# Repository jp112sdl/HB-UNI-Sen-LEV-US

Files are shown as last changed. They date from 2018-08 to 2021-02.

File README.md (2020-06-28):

# HB-UNI-Sen-LEV-US
#### Füllstandsensor für HomeMatic

Um die Geräteunterstützung zu aktivieren, wird die aktuellste Version des [JP-HB-Devices Addon](https://github.com/jp112sdl/JP-HB-Devices-addon/releases/latest) benötigt!
<br/>
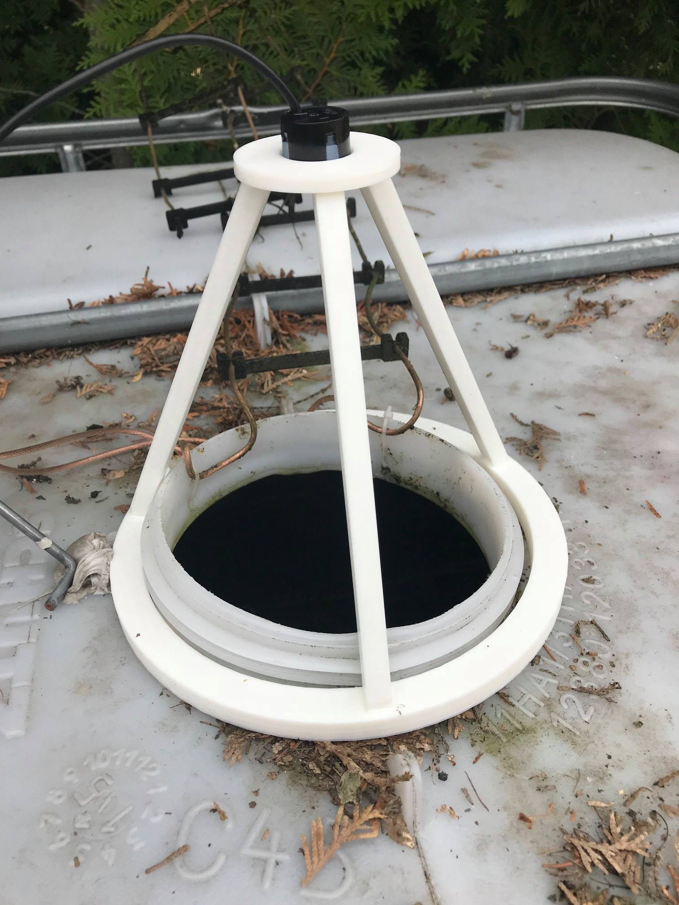
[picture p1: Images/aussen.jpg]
<br/>
_Der erste Prototyp_

#### Bauteile
- Batteriehalter für 3 oder 4 Batterien
- Ultraschallsensor:
  - z.B. [JSN-SR04T V2.0](https://de.aliexpress.com/item/Integrated-Ultrasonic-Module-Distance-Measuring-Sensor-Module-Reversing-Radar-Waterproof/32312190912.html)
    - **Hinweis:** Unbedingt die **V2.0** nehmen, weil diese auch mit 3.3V zuverlässig arbeitet!
  - oder [US-100](https://eckstein-shop.de/Adafruit-US-100-Ultrasonic-Distance-Sensor-3V-or-5V-Logic)  
  - oder MaxBotix [MaxSonar MB1040, LV-MaxSonar-EZ4](https://de.aliexpress.com/item/NEW-Mini-uav-obstacle-avoidance-ultrasonic-ranging-module-MB1040-High-Performance-Sonar-Range-Finder/32862912642.html)
  
- [CC1101 (868MHz)](https://de.aliexpress.com/item/CC1101-Wireless-Module-Long-Distance-Transmission-Antenna-868MHZ-M115-For-FSK-GFSK-ASK-OOK-MSK-64/32635393463.html) 
- [Arduino Pro Mini 3.3V/8MHz](https://de.aliexpress.com/item/Free-Shipping-1pcs-pro-mini-atmega328-Pro-Mini-328-Mini-ATMEGA328-3-3V-8MHz-for-Arduino/32342672626.html)
- Kleinteile...
  - 1x LED
  - 1x Taster
  - Widerstände, je 1x 330 Ohm, 100kOhm, 470kOhm

#### Verdrahtung
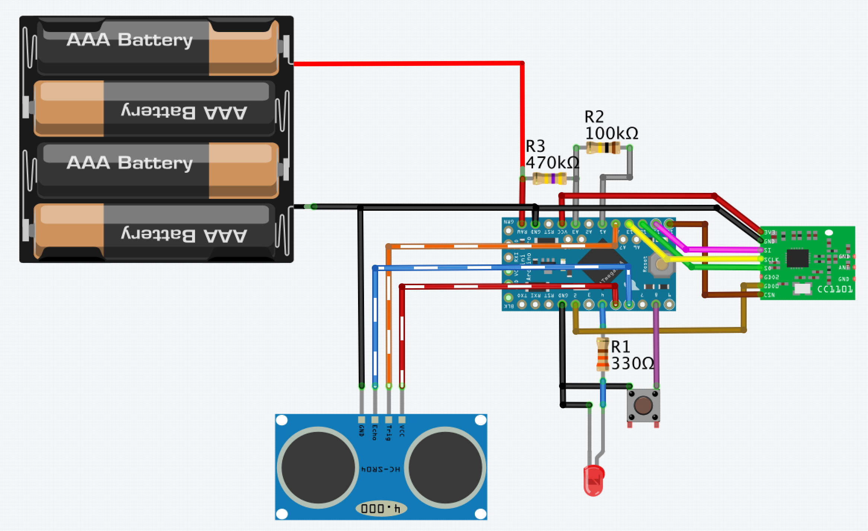
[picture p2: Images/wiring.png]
wiring


**oder mit Temperaturkompensation:**
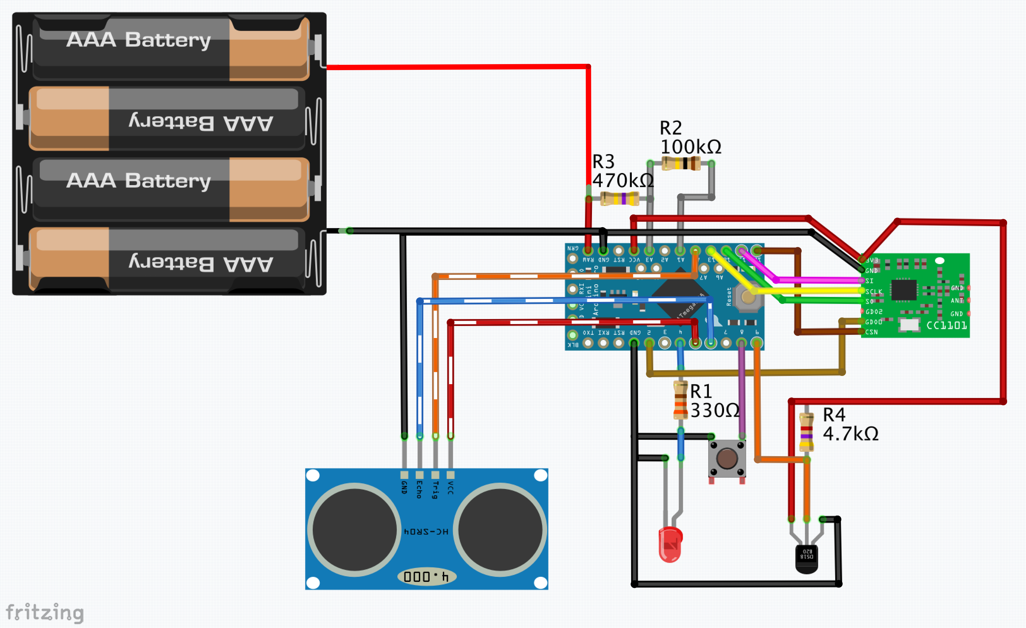
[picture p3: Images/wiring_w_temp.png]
wiring_w_temp


**Bei Verwendung des MaxSonar Sensors ist der PW-Pin an den SENSOR_ECHO_PIN anzuschließen. Der SENSOR_TRIG_PIN wird nicht verwendet.**

#### CCU Geräteeinstellungen
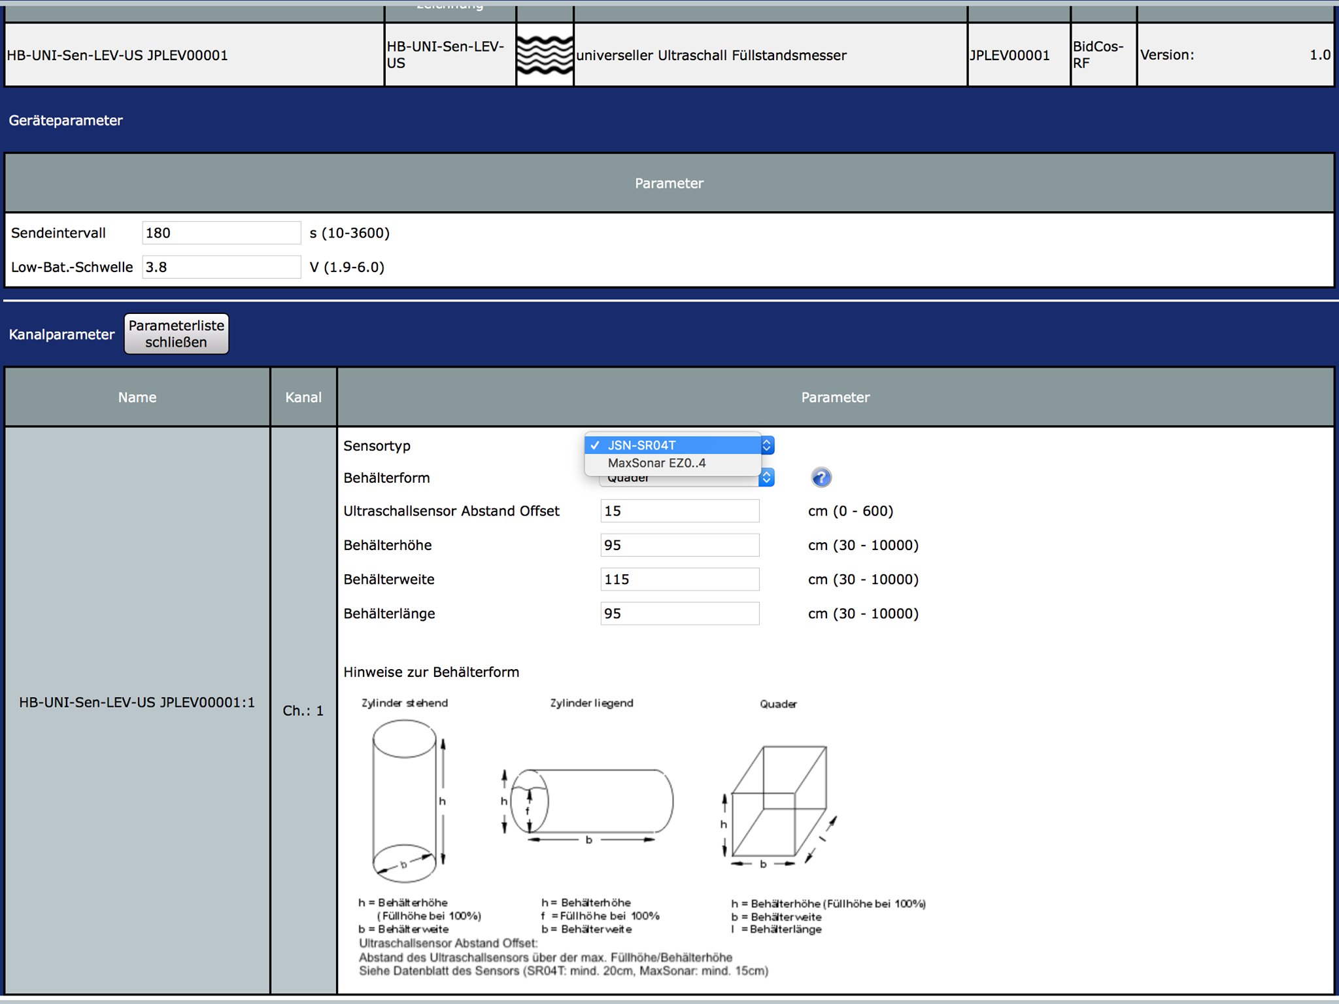
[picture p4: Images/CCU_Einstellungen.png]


Bei Verwendung des **US-100** ist der **JSN-SR04T** auszuwählen

#### CCU Anzeige der Werte
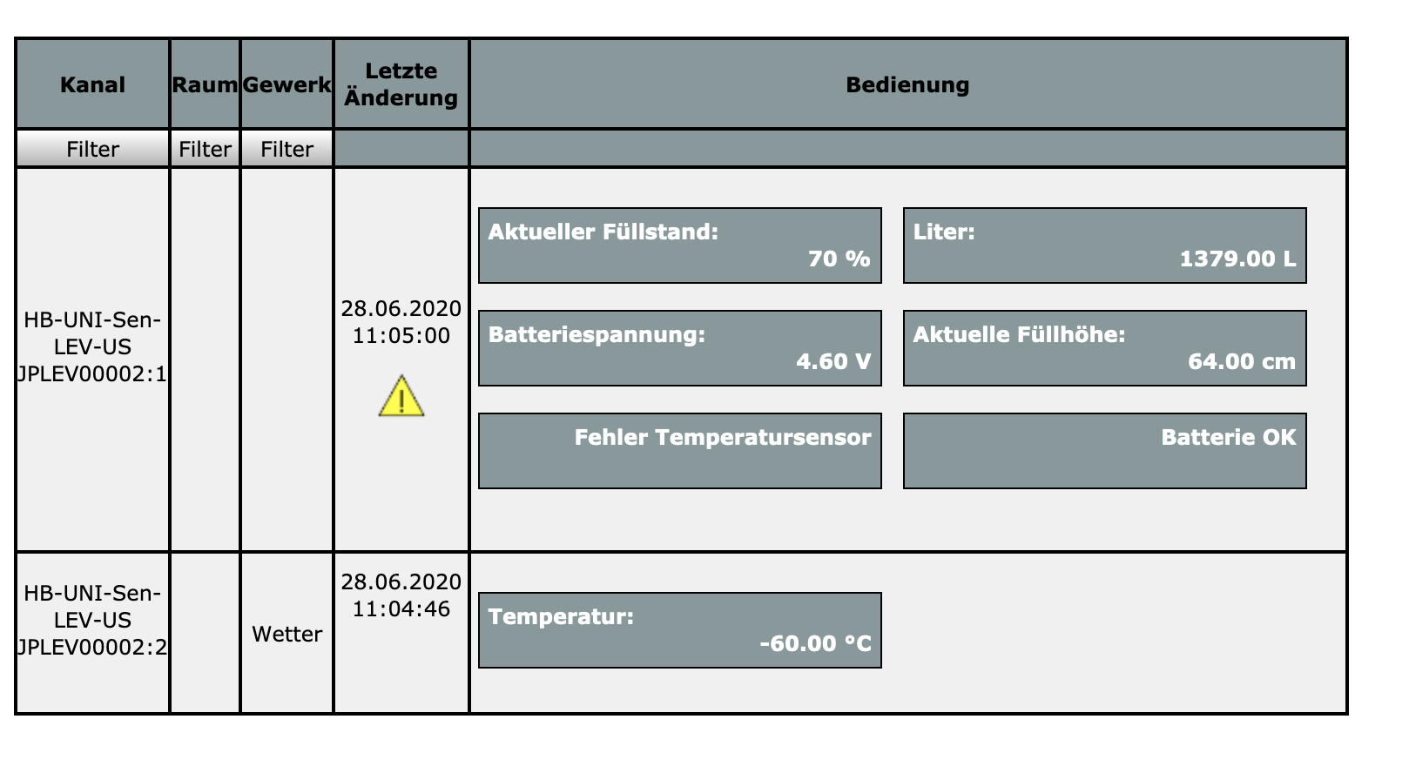
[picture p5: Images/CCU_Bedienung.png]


#### Halterung / Aufhängung
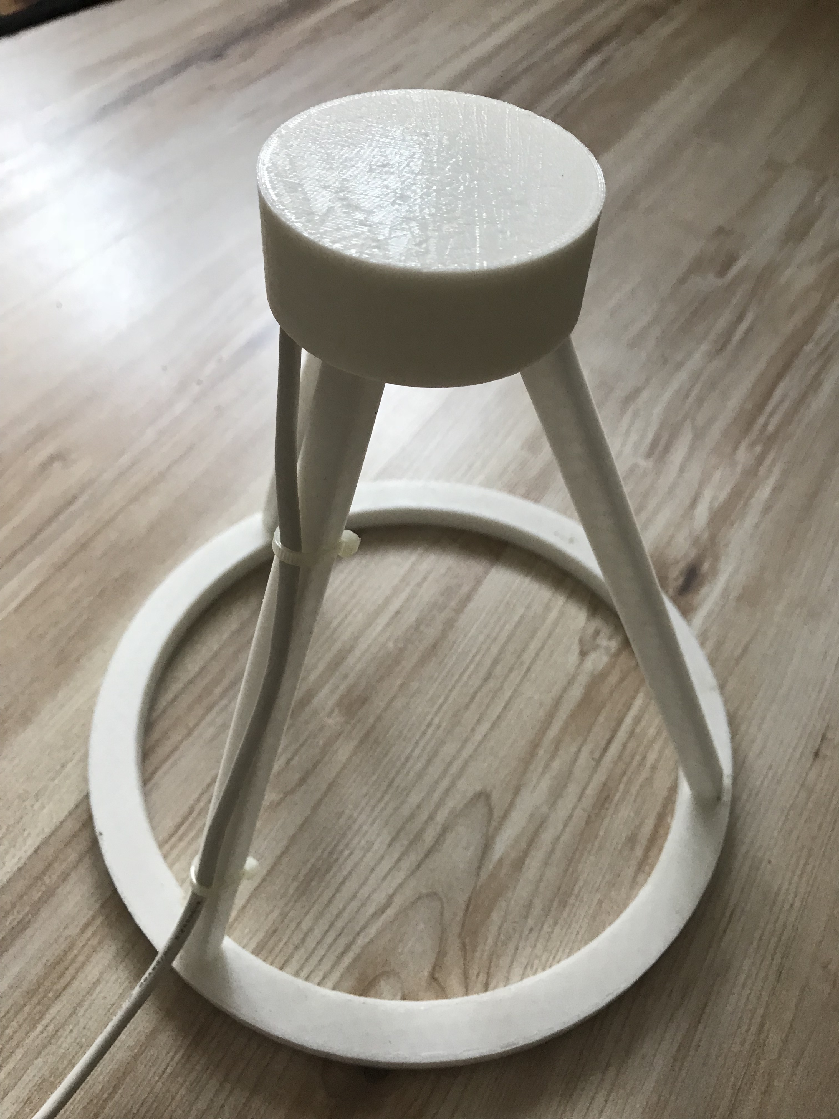
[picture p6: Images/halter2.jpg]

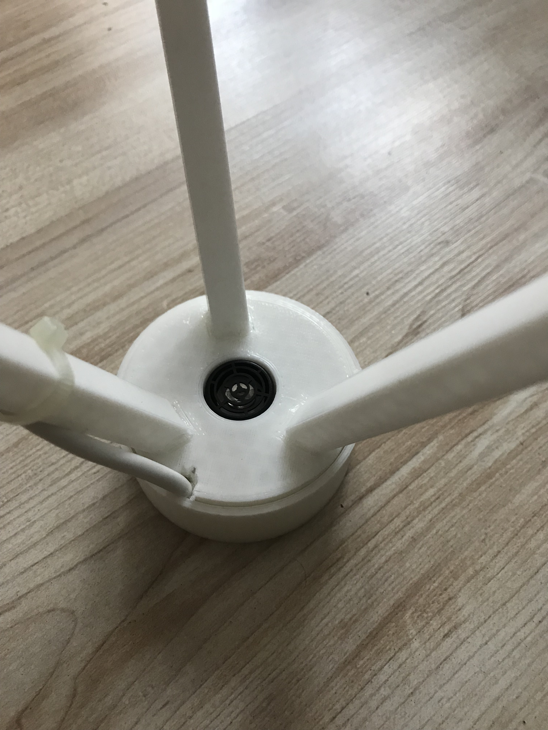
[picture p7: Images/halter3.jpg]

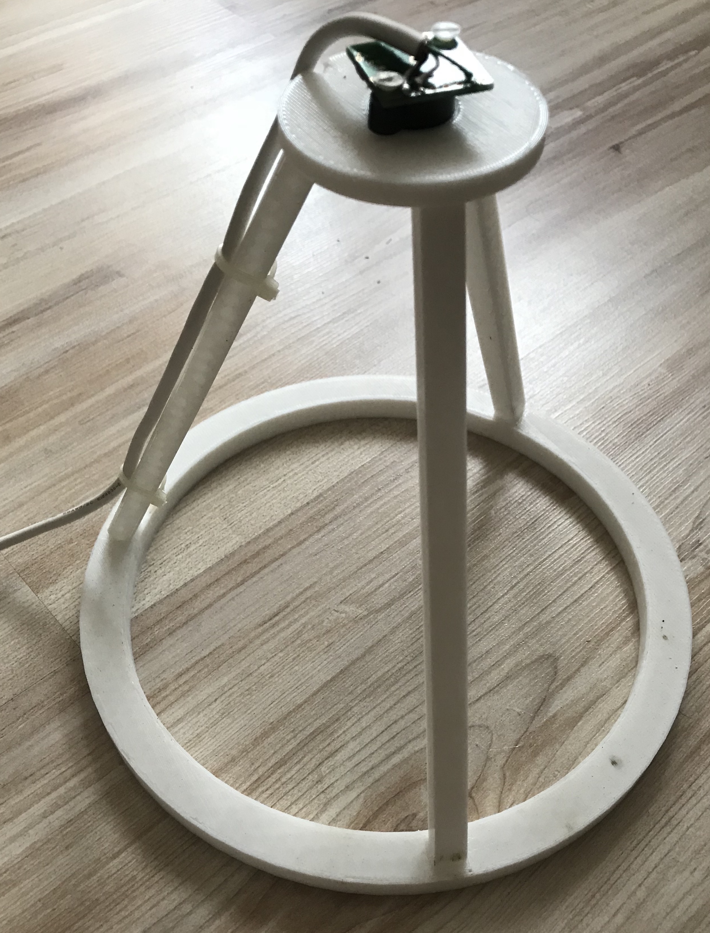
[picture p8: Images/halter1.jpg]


**Die Teile findet ihr bei Tinkercad:**
<br/>
[Stange für Höhe 20cm](https://www.tinkercad.com/things/iM7Yyc3prMh-ultraschallsensor-halterung-stange-20cm-hohe/editv2)<br/>
[Stange für Höhe 15cm](https://www.tinkercad.com/things/7xHuCkIllsB-ultraschallsensor-halterung-stange-15cm/editv2)<br/>
[Ringe](https://www.tinkercad.com/things/15f2ttggOnX-ultraschallsensor-halterung/editv2)<br/>
[Deckel](https://www.tinkercad.com/things/2bYtNM8HQ3f-ultraschallsensor-halterung-deckel/editv2)

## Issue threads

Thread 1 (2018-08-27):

kleine Anmerkungen zur Doku und Sensor

harvey637, 2018-08-27:
Hi Jerome,,
Klugscheisseralarm === winzige Anmerkung zur Doku
- ist MaxBotix == MaxSonar? bei den US-Wandlern steht MaxBotix, im unteren Text "Bei Verwendung des MaxSonar ...". Das kann Kleingeister eventuell verwirren.

- In dem Screenshot der Einstellungsseite steht unten "Siehe Datenblatt des Sensor SR04T: mind 20 cm...".
Trotzdem ist im Beispiel "SR04T" ausgewählt und "15 cm" eingetragen.

Nur so zum "alles richtig verständlich" machen, definitiv vielen Dank und keine Abwertung gemeint!!!
cu
Harvey

PS - ein paar Fragen:
- spielt die Temperatur keine Rolle? (schon minimal bei der Schallgeschwindigkeit:-)
- Fehlmessung etwa durch Plätschern beim Zulauf z.B. in einen Regenwassertank? 2*messen / Mittelwert?
- Einschränkung des Messwinkels um z.B. Zulauf-Wasserstrahl nicht zu erfassen (10cm Durchmesser Rohr?)

jp112sdl, 2018-08-27:
- MaxBotix ist der Hersteller, MaxSonar der Produktname (bzw. der Name der Produktfamilie)
- der Screenshot ist halt so... 🤓 der Offset muss individuell eingestellt werden.

- Temperatur ist bei den Distanzen wohl zu vernachlässigen, ich lass mich aber auch gern belehren, falls es Vorschläge zur Einberechnung gibt. Bisher stimmt die Abstandsmessung bei mir auf den Zentimeter genau

Generell sind die Projekte hier nach meinen persönlichen Anforderungen entstanden und "wie sie sind" veröffentlicht (in Bezug auf die letzten beiden Punkte). Sollten Anpassungen wegen eigener Bedürfnisse notwendig werden (denn irgendwie hat jeder andere Umgebungen), ist es dann wohl am besten, mit Forks zu arbeiten.

VG Jérôme

harvey637, 2018-08-27:
Hi,
mir geht es auch so, für die eigene Anforderung, da hat man ja ein Testumfeld in Praxis.
Bei mir eine Regenwassertonne. Schon der zweite Homematicsensor defekt - Schwitzwasser und
die Platine sitzt so flach, dass der kleinste Wassertropfen reicht :-(

Als ich damals nach Ideen googlete (vor homematic) fand ich eben auch eine Temperaturkompensation.
Ist ja vielleicht auch in dem Modul selbst eingebaut ... vielleicht.
Daher auch die Frage nach dem Winkel: bei mir strömt Wasser aus dem Regenfallrohr bei starkem
Regen sehr "intensiv" in die Tonne. Es gibt den Wasser"fall" mitten durch den Raum oberhalb
der Wassers, eventuell durch den Bereich, den der US-Sensor für die Messung braucht. Da war die
damalige Informationslage, dass der Sensor in eiem normalen 10cm Rohr oben drauf ist, das Rohr ein
paar seitliche Löcher hat damit der Wasserspiegel ansteigen kann und nur INNERHALB des Rohres
reflexionsarm die Oberfläche gemessen wird.
Teile sind in Bestellung :-) Und ich sehe mir das dann gerne "nach persönlichen Anforderungen" an.
Ergibt sich was interessantes melde ich mich hier, sonst ist alles ok!

Wenn ich doch nur mehr von Methoden und Templates verstehen würde, bin halt alter > 64 Jahre
Assemblerprogrammierer. Aber so ein Dutzend HB-Sensoren laufen schon, teils eben mit "persönlichen Anforderungen" modifiziert, die meist uninteressant sind.

Aber das Gesamtthema "Produktsicherheit" (Unterspannung fürhte bei mir zweimal zu Dutycycle mit
Verlust der Geräteverbindung), eben auch "Messung Wasserspiegel" und nicht "Messung was immer da so rumfliegt". Stetz zu wiederholen, ich achte die freiwillige Arbeit hier sehr und möchte nur - ohne zu stören - auch was zurückliefern.
cu
Haarvey

harvey637, 2018-08-27:
Ach, auf den Fotos kann ich auch erkennen, das derjenige auch anscheinend ähnlich schlechte
Erfahrungen mit dem kapazitiven HM-Füllstandssensor hat, die Kabel mit den Abstandhaltern
ist ja gut zu erkennen.

jp112sdl, 2018-08-27:
Derjenige bin ich... 😄
Der kap. Sensor hat mich sehr enttäuscht. Deshalb nun der Versuch mit Ultraschall.

Closed 2018-08-27.

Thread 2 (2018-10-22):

In function 'void setup()':  HB-UNI-Sen-LEV-US:318:19: error: 'printDeviceInfo' was not declared in this scope

fastsonic, 2018-10-22:
Hi,
not sure how to fix:
Version of Arduino 1.8.7
Error:
C:\xxxxxxxxxxxxxxxxxxxxxxxxxxxxxxxxxx\HB-UNI-Sen-LEV-US-4d6f7bfa74beb84f3a6f04ccf81aa3cc47c522d0\HB-UNI-Sen-LEV-US\HB-UNI-Sen-LEV-US.ino: In function 'void setup()':

HB-UNI-Sen-LEV-US:318:19: error: 'printDeviceInfo' was not declared in this scope

jp112sdl, 2018-10-22:
Hi,

just comment line [#318](https://github.com/jp112sdl/HB-UNI-Sen-LEV-US/blob/4d6f7bfa74beb84f3a6f04ccf81aa3cc47c522d0/HB-UNI-Sen-LEV-US.ino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):
`//printDeviceInfo();`

Closed 2018-10-23.

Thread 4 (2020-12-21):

jp112sdl / HB-UNI-Sen-LEV-US

Passagier, 2020-12-21:
Hallo Jerome,

ich habe den HB-UNI-Sen-LEV-US nachgebaut wie so einige andere Projekte von Dir auch -  und aktuelle Versionen verwendet, funktioniert alles sehr sehr gut, allerdings habe ich ein kleines Problem nur bei dem HB-UNI-Sen-LEV-US, wenn ich die Werte für Sendeintervall und oder Low-Bat.-Schwelle ändern möchte, werden diese tatsächlich nicht übernommen, es bleibt bei den Defaultwerten Sendeintervall= 180 und Low-Bat.-Schwelle= 2.2
wie kann ich das beheben?

Beste Grüße

jp112sdl, 2020-12-21:
Nutzt du gerade CCU FW 3.55.5 ?
Da ist ein Bug drin... du kannst bei keinem Gerät irgendwelche Werte mehr ändern

Passagier, 2020-12-21:
Ja ich habe die CU FW 3.55.5,
stimmt, habe ich gerade beim HB-UNI-Sen-TEMP-DS18B20 probiert gleiches Problem...
dachte dass er da die Werte übernommen hatte..
Allerdings kann ich die anderen Werte wie Höhe und Breite beim HB-UNI-Sen-LEV-US problemlos ändern
Ist der Bug behebbar oder gibt es ein Workarround?

jp112sdl, 2020-12-21:
Workaround: webui.js patchen
https://github.com/jens-maus/RaspberryMatic/blob/master/buildroot-external/patches/occu/0098-WebUI-Fix-ProofAndSetValue.patch

Ansonsten auf neue CCU FW warten, oder Downgrade machen

Passagier, 2020-12-21:
Sehr guter Tipp, danke hat funktioniert. 👍

Passagier, 2020-12-23:
Hallo Jerome,
ich muss noch einmal nachhacken,
Nach dem patchen der Webui, kann ich die Konfigurationsdaten eintragen und senden, diese werden aber erst übernommen, wenn ich kurzdarauf den Configbuttion am HB-UNI-Sen-LEV-US betätige oder es kurz vom Strom nehme und dadurch neu gestartet wird, sonst geht die Config nicht durch, woran kann das noch liegen?

jp112sdl, 2020-12-23:
Hast du keine originalen HM Sensoren?

Das ist übliches Verhalten von batterieversorgten Homematic Sensoren.

Passagier, 2020-12-23:
Nein, alles auf HMIP, ausser den Prijekten von Dir,
diese habe ich mit Arduino Nano‘s mit Dauerstrom über USB
im Einsatz, hat bisher sehr gut funktioniert,
Originale HM‘s hab ich keine.

Passagier, 2020-12-23:
Wünsche Frohe Weihnachten und ein schönes gesundes Fest!

jp112sdl, 2020-12-23:
Dankeschön, das wünsche ich dir auch

Passagier, 2020-12-23:
Danke!

Closed 2020-12-22.

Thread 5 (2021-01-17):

Probleme bei der Messung

ednarb29, 2021-01-17:
Hallo Jérôme,

Vielen Dank für deine Projekte und deinen Code. Ich bin gerade dabei, diesen Anwendungsfall nachzubauen, da mein Vater ein Wassertank im Keller hat, den er gerne überwachen möchte.

Allerdings stoße ich dabei auf ein Problem bei der Messung. Der Sensor ist oben am Tank angebracht, und der Tank ist auf einem Abstand vom Sensor von etwa 100cm mit einer ersten Verengung versehen, die der Sensor konstant aufgreift. Diese Verengung ist rund und hat einen Durchmesser von etwa 80cm. Eine weitere Verengung ist weiter unten angebracht. Die maximale Distanz, die der Sensor messen muss, beträgt 160cm. Auf dieser Entfernung sollten 15 Grad Messbereich also 42cm ausmachen, was nur die Hälfte der Verengung darstellt.

Hast du eine Idee, warum der Sensor permanent die erste Verengung aufgreift und was das Problem sein könnte? Die 15 Grad auf die Entfernung dürften es eigentlich nicht sein.

Ich habe einen US-100 mit dem Pro Mini verwendet, habe aber auch einen HC-SR04 mit einem Uno und Display Shield testweise in den Tank gehalten - gleiches Problem. Denkst du, ich kann das mit diesem Sensor lösen, oder sollte ich lieber auf den VL53L0X ausweichen (mein Messbereich liegt zwischen 10-160cm etwa).

Danke und Grüße,
Steven

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

jp112sdl, 2021-01-17:
Puh, das ist eine schwierige Frage, die ich dir nicht beantworten kann.

Die Tücken der Ultraschallmessungen kenne ich nicht bis ins Detail.
Vielleicht gibt es im Netz irgendwo ein "Ultraschallsensoren-Forum" ? :)

Zum VL53L0X kann ich nur sagen, dass du eine reflektierende Oberfläche benötigst.
Evtl. ein 100er Rohr reinstellen bis kurz über dem Boden. Dann eine dünne Styroporplatte drinnen auf der Wassersäule schwimmen lassen und den VL53L0X wirklich exakt senkrecht darüber positionieren.

Eine weitere Möglichkeit wäre vielleicht noch den Druck zu messen.
Der Tank hat einen Anschluss unten rechts auf dem ersten Bild?

ednarb29, 2021-01-17:
Danke für deine schnelle Antwort. Ja, das ist der Anschluss, wo die Pumpe das Wasser abnimmt.

ednarb29, 2021-01-23:
@jp112sdl, ich habe nochmal recherchiert zu dem Sensor und [diesen Artikel hier gefunden](https://wolles-elektronikkiste.de/vl53l0x-und-vl53l1x-tof-abstandssensoren). Auch in mehreren Datenblättern habe ich eine maximale (verlässliche) Reichweite von 1m bei dem vl53l0x gefunden. Der vl53l1x scheint aber eine gute Alternative zu sein. Im Keller ist es komplett dunkel, und ich möchte es mit einer schwimmenden Styroporplatte probieren.

[Den Sensor gibt es zum Beispiel hier zu kaufen.](https://eckstein-shop.de/Pololu-VL53L1X-Time-of-Flight-Distance-Sensor-Carrier-with-Voltage-Regulator-400cm-Max)

Ich würde den Sensor gerne ausprobieren, bin aber nicht in der Lage, den [Sensor-Spezifischen Code](https://github.com/jp112sdl/AskSinPP/tree/master/sensors) anzupassen bzw. zu schreiben. Kann ich den Sensor mit deinem Projekt Code [HB-UNI-Sen-LEV-TOF](https://github.com/jp112sdl/HB-UNI-Sen-LEV-TOF) und dem dort verwendeten [Sensor Vl53l0x Code](https://github.com/jp112sdl/AskSinPP/blob/master/sensors/Vl53l0x.h) verwenden, oder muss dazu neuer Code für den Sensor geschrieben werden?

Danke!

jp112sdl, 2021-01-23:
Der VL53L1X wird mit dem Code nicht funktionieren.
Dazu sind größere Umbauten notwendig.

ednarb29, 2021-01-24:
Schade... Hättest du Lust / Zeit das umzusetzen?

jp112sdl, 2021-01-24:
Eher weniger, weil ich die Notwendigkeit gerade nicht sehe.

> Auch in mehreren Datenblättern habe ich eine maximale (verlässliche) Reichweite von 1m bei dem vl53l0x gefunden.

Der Hersteller selbst schreibt nichts davon
https://www.st.com/resource/en/data_brief/vl53l0x.pdf

Der VL53L0X kostet auch keine 2 EUR https://de.aliexpress.com/item/32849648943.html
Daher solltest du es vielleicht erstmal mit dem Sensor probieren

ednarb29, 2021-01-25:
Alles klar, dann probiere ich das mit dem Sensor und wenn es nicht geht verwerfe ich das Projekt. Danke trotzdem für deine kurze Antwortzeit und Unterstützung! :)

ednarb29, 2021-01-29:
Habe es jetzt mit dem VL53L0X Sensor probiert und er misst tatsächlich nur bis 120cm, danach zeigt er "out of range" an. Damit kann ich das leider nicht für mein Fass verwenden, da ich etwa 150-160cm benötige, schade.

Bitte lass mich wissen, falls du irgendwann den anderen Sensor unterstützt, dann würde ich es wieder probieren.

Danke und Grüße,
Steven

`#include <LiquidCrystal.h>
LiquidCrystal lcd(8, 9, 4, 5, 6, 7);  // select the pins used on the LCD panel

#include "Adafruit_VL53L0X.h"

Adafruit_VL53L0X lox = Adafruit_VL53L0X();

void setup() {
  Serial.begin(115200);

  lcd.begin(16, 2);

  // wait until serial port opens for native USB devices
  while (! Serial) {
    delay(1);
  }

  Serial.println("Adafruit VL53L0X test");
  if (!lox.begin()) {
    Serial.println(F("Failed to boot VL53L0X"));
    while(1);
  }
  // power
  Serial.println(F("VL53L0X API Simple Ranging example\n\n"));
}

void loop() {
  VL53L0X_RangingMeasurementData_t measure;

  Serial.print("Reading a measurement... ");
  lox.rangingTest(&measure, false); // pass in 'true' to get debug data printout!

  lcd.clear();
  lcd.setCursor(0,0);

  if (measure.RangeStatus != 4) {  // phase failures have incorrect data
    Serial.print("Distance (mm): "); Serial.println(measure.RangeMilliMeter);
    lcd.print("D: ");
    lcd.print(measure.RangeMilliMeter,1);
  } else {
    Serial.println(" out of range ");
    lcd.print(" out of range ");
  }

  delay(500);
}`

ednarb29, 2021-01-29:
Hier steht, dass man long range bis 200cm nutzen kann - wie aktiviert man den?

https://www.adafruit.com/product/3317

ednarb29, 2021-01-29:
Hi, habe es jetzt mit dem VL53L0X probiert. Im einfachen Modus geht er nur bis 120cm, mit diesem Code hier geht er allerdings in den Long Range Modus und bis 200cm. Das ist das, was ich bräuchte. Unterstützt du das in deinem Code auch?

https://github.com/adafruit/Adafruit_VL53L0X/blob/master/examples/vl53l0x_multi_extended/vl53l0x_multi_extended.ino

jp112sdl, 2021-01-29:
> Unterstützt du das in deinem Code auch?

Ja der LONG_RANGE Modus wird standardmäßig verwendet
https://github.com/jp112sdl/HB-UNI-Sen-LEV-TOF/blob/ae6d07fb8a74e5c2d791c49386c9ada14d37d033/HB-UNI-Sen-LEV-TOF.ino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

ednarb29, 2021-01-29:
Super, danke dir. Dann löte ich das jetzt mal zusammen und probiere es aus. :)

ednarb29, 2021-01-29:
Ich habe die batterie am RAW und GND pin vom Pro Mini. Schließe ich den Sensor dann an GND, VCC, und A4, A5 an wie hier beschrieben?

https://www.extrafudge.com/site/2019/03/arduino-pro-mini-sda-and-scl-pins/

ednarb29, 2021-01-29:
Habe es jetzt so angelötet und probiert. Musste eine Library für den VL53L0X von Pololu installiert, sonst hat er sich beschwert, dass die VL53L0X.h fehlt. Ist das die korrekte Lib? Vielleicht in die Readme aufnehmen. Oder ich habs irgendwo überlesen.

Allerdings kommt auf dem Serial Monitor nichts an. Wenn ich den Code für den US aufspiele, läuft er los, mit dem Code für den VL53L0X allerdings nicht. Siehe Screenshots. Ideen?

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

jp112sdl, 2021-01-29:
> Vielleicht in die Readme aufnehmen. Oder ich habs irgendwo überlesen.

Ist ein bisschen versteckt
https://github.com/pa-pa/AskSinPP/blob/a836a356103f4a6d1d1ca9517347f145a2b25b26/sensors/Vl53l0x.h#L26

> Allerdings kommt auf dem Serial Monitor nichts an.

https://github.com/jp112sdl/HB-UNI-Sen-LEV-TOF/blob/ae6d07fb8a74e5c2d791c49386c9ada14d37d033/HB-UNI-Sen-LEV-TOF.ino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
I2C Adresse 0x29 passt?

ednarb29, 2021-01-29:
Das weis ich nicht. Wie kann ich das kontrollieren bzw. wie weis ich ob die stimmt?

jp112sdl, 2021-01-29:
I2CScanner probieren.
https://playground.arduino.cc/Main/I2cScanner/

Hab momentan wenig Zeit

ednarb29, 2021-01-29:
Kein Problem. Ich schaue es mir morgen mal an. Danke vielmals.

Vielleicht hat es auch was mit der Kabellänge zu tun. Habe ein cat7 Ethernet Kabel in den Keller gelegt und den Arduino einen Stock drüber (3m Kabel) wegen dem Funkempfang. Mit dem US ging es problemlos, aber vielleicht macht es das I2C nicht mit...

jp112sdl, 2021-01-30:
> Habe ein cat7 Ethernet Kabel in den Keller gelegt und den Arduino einen Stock drüber (3m Kabel) wegen dem Funkempfang.

```
 So the maximum bus length of an I2C link is about 1 meter at 100 Kbaud
```
http://www.mosaic-industries.com/embedded-systems/sbc-single-board-computers/freescale-hcs12-9s12-c-language/instrument-control/i2c-bus-specifications

100k ist die Standardübertragungsrate (beim Arduino)

ednarb29, 2021-01-30:
Danke dir. Habe das Kabel abgeschnitten und so kurz wie möglich gemacht. Mit knapp 1,5m geht es. Auch der Sensor scheint zu funktionieren und korrekt zu messen. Habe eine Styroporplatte an einer Angelschnur und einem Gewicht am Boden des Fasses befestigt, um eine beweglicht Fläche zu haben.

Alles in allem funktioniert es jetzt jedenfalls. Nochmals vielen Dank für deine Unterstützung!

Closed 2021-01-30.

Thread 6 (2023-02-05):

Falsche Werte in der Homematic

spottich, 2023-02-05:
Hallo

Habe den Sensor nachgebaut.
Jedoch das Problem das bei einem Messbereich von 0 bis 100 cm bei 50 cm Füllstand, 25 cm Abweichung sind, also 75 cm Füllstand angezeigt werden in der Homematic (Addon ist aktuell) . Ich habe einen Sr04 verwendet, ich kann sicherstellen das dieser funktioniert, über ein Test.ino zeigte er die richtigen Messwerte an.

Wo kann ich ansetzen wegen dieses Problems ?

Grüße

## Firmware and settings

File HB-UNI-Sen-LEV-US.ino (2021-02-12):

//- -----------------------------------------------------------------------------------------------------------------------
// AskSin++
// 2016-10-31 papa Creative Commons - http://creativecommons.org/licenses/by-nc-sa/3.0/de/
// 2018-04-16 jp112sdl Creative Commons - http://creativecommons.org/licenses/by-nc-sa/3.0/de/
// 2020-03-12 Wolfram Winter Creative Commons - http://creativecommons.org/licenses/by-nc-sa/3.0/de/
//- -----------------------------------------------------------------------------------------------------------------------
// ci-test=yes board=328p aes=no

// define this to read the device id, serial and device type from bootloader section
// #define USE_OTA_BOOTLOADER

#define USE_TEMPERATURE_COMPENSATION // connect DS18B20 Sensor to Pin 9
#define SENSOR_ONLY

#define EI_NOTEXTERNAL
#include <EnableInterrupt.h>
#include <AskSinPP.h>
#include <LowPower.h>

#include <Register.h>
#include <MultiChannelDevice.h>
#ifdef USE_TEMPERATURE_COMPENSATION
#include <OneWire.h>
#include <sensors/Ds18b20.h>
#endif

// Arduino Pro mini 8 Mhz
// Arduino pin for the config button
#define CONFIG_BUTTON_PIN  8
#define LED_PIN            4

#define SENSOR_EN_PIN      5 //VCC Pin des Sensors
#define SENSOR_ECHO_PIN    6
#define SENSOR_TRIG_PIN    14 //A0
#define BATT_EN_PIN        15
#define BATT_SENS_PIN      17
#define DS18B20_PIN        9

#ifdef USE_TEMPERATURE_COMPENSATION
//DS18B20 Sensors connected to pin
OneWire oneWire(DS18B20_PIN);
#endif

// number of available peers per channel
#define PEERS_PER_CHANNEL 2

// all library classes are placed in the namespace 'as'
using namespace as;

//Korrekturfaktor der Clock-Ungenauigkeit, wenn keine RTC verwendet wird
#define SYSCLOCK_FACTOR    0.88
#define MAX_MEASURE_COUNT  5

enum UltrasonicSensorTypes {
  JSN_SR04T_US100,
  MAXSONAR
};

// define all device properties
const struct DeviceInfo PROGMEM devinfo = {
  {0xF9, 0xD2, 0x01},          // Device ID
  "JPLEV00001",                // Device Serial
  {0xF9, 0xD2},                // Device Model
#ifdef USE_TEMPERATURE_COMPENSATION
  0x12,                        // Firmware Version
#else
  0x11,
#endif
  0x53,                        // Device Type
  {0x01, 0x01}                 // Info Bytes
};

/**
   Configure the used hardware
*/
typedef AskSin<StatusLed<LED_PIN>, BatterySensorUni<BATT_SENS_PIN, BATT_EN_PIN, 0>, Radio<AvrSPI<10, 11, 12, 13>, 2>> BaseHal;
class Hal : public BaseHal {
  public:
    void init (const HMID& id) {
      BaseHal::init(id);
      battery.init(seconds2ticks(60UL * 60) * SYSCLOCK_FACTOR, sysclock); //battery measure once an hour
      battery.low(22);
      battery.critical(20);
    }

    bool runready () {
      return sysclock.runready() || BaseHal::runready();
    }
} hal;


DEFREGISTER(UReg0, MASTERID_REGS, DREG_LOWBATLIMIT, 0x20, 0x21)
class UList0 : public RegList0<UReg0> {
  public:
    UList0 (uint16_t addr) : RegList0<UReg0>(addr) {}

    bool Sendeintervall (uint16_t value) const {
      return this->writeRegister(0x20, (value >> 8) & 0xff) && this->writeRegister(0x21, value & 0xff);
    }
    uint16_t Sendeintervall () const {
      return (this->readRegister(0x20, 0) << 8) + this->readRegister(0x21, 0);
    }

    void defaults () {
      clear();
      lowBatLimit(22);
      Sendeintervall(180);
    }
};

DEFREGISTER(UReg1, CREG_CASE_HIGH, CREG_CASE_WIDTH, CREG_CASE_DESIGN, CREG_CASE_LENGTH, 0x01, 0x02, 0x03)
class UList1 : public RegList1<UReg1> {
  public:
    UList1 (uint16_t addr) : RegList1<UReg1>(addr) {}

    bool distanceOffset (uint16_t value) const {
      return this->writeRegister(0x01, (value >> 8) & 0xff) && this->writeRegister(0x02, value & 0xff);
    }
    uint16_t distanceOffset () const {
      return (this->readRegister(0x01, 0) << 8) + this->readRegister(0x02, 0);
    }

    bool sensorType (uint16_t value) const {
      return this->writeRegister(0x03, value & 0xff);
    }
    uint16_t sensorType () const {
      return this->readRegister(0x03, 0);
    }

    void defaults () {
      clear();
      caseHigh(100);
      caseWidth(100);
      caseLength(100);
      caseDesign(0);
      distanceOffset(0);
      sensorType(0);
    }
};

class MeasureEventMsg : public Message {
  public:
    void init(uint8_t msgcnt, uint8_t percent, uint32_t liter, uint16_t height, uint8_t volt, int16_t temp) {
      // Message Length (first byte param.): 11 + payload = 17 = 0x11
      uint8_t msg_len = 0x11;
#ifdef USE_TEMPERATURE_COMPENSATION
      msg_len += 0x03; // three extra bytes for the temperature channel
#endif
      Message::init(msg_len, msgcnt, 0x53, BIDI | WKMEUP, percent & 0xff, volt & 0xff);
      pload[0] = (liter >>  24) & 0xff;
      pload[1] = (liter >>  16) & 0xff;
      pload[2] = (liter >>  8) & 0xff;
      pload[3] = liter & 0xff;
      pload[4] = (height >> 8) & 0xff;
      pload[5] = height & 0xff;
#ifdef USE_TEMPERATURE_COMPENSATION
      pload[6] = 0x42;
      pload[7] = (temp >> 8) & 0xff;
      pload[8] = temp & 0xff;
#endif
    }
};

class MeasureChannel : public Channel<Hal, UList1, EmptyList, List4, PEERS_PER_CHANNEL, UList0>, public Alarm {
    MeasureEventMsg msg;
    uint8_t  fillingPercent;
    uint32_t fillingLiter;
    uint16_t fillingHeight;
    uint16_t distance;
    int16_t temperature;
    uint8_t sensorCount;

    uint8_t last_flags = 0xff;

#ifdef USE_TEMPERATURE_COMPENSATION
    Ds18b20 tempSensors[1];
#endif

  public:
    MeasureChannel () : Channel(), Alarm(0), fillingPercent(0), fillingLiter(0), fillingHeight(0), distance(0), temperature(-600), sensorCount(0) {}
    virtual ~MeasureChannel () {}

    void measure() {
      uint32_t caseHeight = this->getList1().caseHigh();
      uint32_t caseWidth = this->getList1().caseWidth();
      uint32_t caseLength = this->getList1().caseLength();
      uint32_t caseDesign  = this->getList1().caseDesign();
      uint32_t distanceOffset = this->getList1().distanceOffset();

      uint32_t m_value = 0;
      uint32_t duration = 0;
      uint8_t validcnt = 0;


      pinMode(SENSOR_ECHO_PIN, INPUT_PULLUP);
      _delay_ms(300);
      digitalWrite(SENSOR_EN_PIN, HIGH);
      _delay_ms(300);
      switch (this->getList1().sensorType()) {
        case JSN_SR04T_US100:
        {
          digitalWrite(SENSOR_TRIG_PIN, LOW);
          delayMicroseconds(2);
          digitalWrite(SENSOR_TRIG_PIN, HIGH);
          delayMicroseconds(10);
          digitalWrite(SENSOR_TRIG_PIN, LOW);

          duration = pulseIn(SENSOR_ECHO_PIN, HIGH);

          validcnt++;
        }
          break;
        case MAXSONAR:
        {
          pulseIn(SENSOR_ECHO_PIN, HIGH);
          _delay_ms(100);
          for (uint8_t i = 0; i < MAX_MEASURE_COUNT; i++) {
            uint16_t p =  pulseIn(SENSOR_ECHO_PIN, HIGH);
            if (p < 35750) {
              duration += p;
              validcnt++;
            } else {
              DPRINTLN("Invalid range detected!");
            }
            _delay_ms(100);
          }

        }
          break;
        default:
          DPRINTLN(F("Invalid Sensor Type selected"));
          break;
      }

      digitalWrite(SENSOR_EN_PIN, LOW);
      pinMode(SENSOR_ECHO_PIN, INPUT);

      duration = (validcnt > 0) ? duration / validcnt : 0;

      m_value = (duration * 1000L / 57874L);

      DPRINT("DIST UNCOMP = "); DDECLN(m_value);
#ifdef USE_TEMPERATURE_COMPENSATION
      if (sensorCount > 0) {
        Ds18b20::measure(tempSensors, sensorCount);
        temperature = tempSensors[0].temperature();
        DPRINT("TEMPERATURE = ");DDECLN(temperature);
        uint32_t speedOfSound = 3313L + (606L * temperature) / 1000L;
        uint32_t compensatedDistance = ((duration * 100000L / 20000) * speedOfSound) / 1000000L;
        DPRINT("DIST   COMP = "); DDECLN(compensatedDistance);
        m_value = compensatedDistance;
      }
#endif
      DPRINTLN("");
      DPRINT(F("Abstand gemessen         : ")); DDECLN(m_value);
      distance = (distanceOffset > m_value) ? 0 :  m_value - distanceOffset;
      DPRINT(F("Abstand abzgl. OFFSET    : ")); DDECLN(distance);

      DPRINT(F("Behaelterhoehe           : ")); DDECLN(caseHeight);
      fillingHeight = (distance > caseHeight) ? 0 : caseHeight - distance;
      DPRINT(F("Fuellhoehe               : ")); DDECLN(fillingHeight);

      uint32_t caseVolume = 0; float r = 0;
      switch (caseDesign) {
        case 0:
          caseVolume = (PI * pow((caseWidth >> 1), 2) * caseHeight) / 1000L;
          fillingLiter = (PI * pow((caseWidth >> 1), 2) * fillingHeight) / 1000L;
          break;
        case 1:
          caseVolume = (PI * pow((caseHeight >> 1), 2) * caseWidth) / 1000L;
          //fillingLiter = pow(caseHeight >> 1, 2) * caseWidth * (acos((caseHeight >> 1 - fillingHeight) / caseHeight >> 1) - (caseHeight >> 1 - fillingHeight) * (sqrt((2 * caseHeight >> 1 * fillingHeight) - pow(fillingHeight, 2)) / pow(caseHeight >> 1, 2)))  ;
          r = caseHeight  / 2;
          fillingLiter = (r * r * 2 * acos(1 - fillingHeight / r) / 2 - 2 * sqrt(caseHeight * fillingHeight - fillingHeight * fillingHeight) * (r - fillingHeight) / 2) * caseWidth / 1000L;
          break;
        case 2:
          caseVolume = (caseHeight * caseWidth * caseLength) / 1000L;
          fillingLiter = (fillingHeight * caseWidth * caseLength) / 1000L;
          break;
        default:
          DPRINTLN(F("Invalid caseDesign")); DDECLN(caseDesign);
          break;
      }

      fillingPercent = (fillingLiter * 100) / caseVolume;
      DPRINT(F("Behaeltervolumen (gesamt): ")); DDECLN(caseVolume);
      DPRINT(F("Inhalt                   : ")); DDEC(fillingLiter); DPRINT(F("L (")); DDEC(fillingPercent); DPRINTLN(F("%)"));
      DPRINTLN("");
    }
    virtual void trigger (__attribute__ ((unused)) AlarmClock & clock) {
      uint8_t msgcnt = device().nextcount();
      if (last_flags != flags()) {
        this->changed(true);
        last_flags = flags();
      }
      measure();
      tick = delay();
      msg.init(msgcnt, fillingPercent, fillingLiter, fillingHeight, device().battery().current(), temperature);
      if (msgcnt % 20 == 1) device().sendPeerEvent(msg, *this); else device().broadcastEvent(msg);
      sysclock.add(*this);
    }

    uint32_t delay () {
      uint16_t _txMindelay = 20;
      _txMindelay = device().getList0().Sendeintervall();
      if (_txMindelay == 0) _txMindelay = 20;
      return seconds2ticks(_txMindelay  * SYSCLOCK_FACTOR);
    }

    void configChanged() {
      DPRINTLN(F("Config changed List1"));
      DPRINT(F("*CASE_HIGH:       "));
      DDECLN(this->getList1().caseHigh());
      DPRINT(F("*CASE_WIDTH:      "));
      DDECLN(this->getList1().caseWidth());
      DPRINT(F("*CASE_LENGTH:     "));
      DDECLN(this->getList1().caseLength());
      DPRINT(F("*CASE_DESIGN:     "));
      DDECLN(this->getList1().caseDesign());
      DPRINT(F("*DISTANCE_OFFSET: "));
      DDECLN(this->getList1().distanceOffset());
      DPRINT(F("*SENSOR_TYPE:     "));
      DDECLN(this->getList1().sensorType());
    }

    void setup(Device<Hal, UList0>* dev, uint8_t number, uint16_t addr) {
      Channel::setup(dev, number, addr);
      // pinMode(SENSOR_ECHO_PIN, INPUT_PULLUP);
      pinMode(SENSOR_ECHO_PIN, INPUT);
      pinMode(SENSOR_TRIG_PIN, OUTPUT);
      pinMode(SENSOR_EN_PIN, OUTPUT);

#ifdef USE_TEMPERATURE_COMPENSATION
      sensorCount = Ds18b20::init(oneWire, tempSensors, 1);
      DPRINT("Found "); DDEC(sensorCount); DPRINTLN(" DS18B20 Sensor(s)");
#endif
      sysclock.add(*this);
    }

    uint8_t status () const {
      return 0;
    }

    uint8_t flags () const {
      uint8_t flags = 0x00;

#ifdef USE_TEMPERATURE_COMPENSATION
      if (sensorCount == 0) flags = 0x01 << 1;
#endif

      flags |= this->device().battery().low() ? 0x80 : 0x00;
      return flags;
    }
};

class UType : public MultiChannelDevice<Hal, MeasureChannel, 1, UList0> {
  public:
    typedef MultiChannelDevice<Hal, MeasureChannel, 1, UList0> TSDevice;
    UType(const DeviceInfo& info, uint16_t addr) : TSDevice(info, addr) {}
    virtual ~UType () {}

    virtual void configChanged () {
      TSDevice::configChanged();
      DPRINT(F("*LOW BAT Limit: "));
      DDECLN(this->getList0().lowBatLimit());
      this->battery().low(this->getList0().lowBatLimit());
      DPRINT(F("*Sendeintervall: ")); DDECLN(this->getList0().Sendeintervall());
    }
};

UType sdev(devinfo, 0x20);
ConfigButton<UType> cfgBtn(sdev);

void setup () {
  DINIT(57600, ASKSIN_PLUS_PLUS_IDENTIFIER);
  sdev.init(hal);
  buttonISR(cfgBtn, CONFIG_BUTTON_PIN);
  DDEVINFO(sdev);
  sdev.initDone();
}

void loop() {
  bool worked = hal.runready();
  bool poll = sdev.pollRadio();
  if ( worked == false && poll == false ) {
    if ( hal.battery.critical() ) {
      hal.activity.sleepForever(hal);
    }
    hal.activity.savePower<Sleep<>>(hal);
  }
}

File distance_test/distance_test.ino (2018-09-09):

const int pwPin1 = 6;
long sensor;

void setup() {
  Serial.begin(57600);
  pinMode(5, OUTPUT);
  pinMode(pwPin1, INPUT);
}

void read_sensor () {
  digitalWrite(5, HIGH);
  delay(300);
  sensor = pulseIn(pwPin1, HIGH);
  digitalWrite(5, LOW);

}

void print_range() {
  Serial.print("S1");
  Serial.print("=");
  Serial.print( sensor);
  Serial.print(", ");
  Serial.println( (sensor * 1000L / 57874L));
}

void loop() {
  read_sensor();
  print_range();
  delay(100);
}

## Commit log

2018-08-19 added images
    [wiring.fzz]
2018-11-10 removed printDeviceInfo()
2018-12-05 sleep forever, when battery is critical
2018-12-10 use internal bandgap reference for battery measurement
2020-05-03 update battery values
2020-06-28 add temperature compensation with DS18B20 sensor
    [wiring.fzz]
